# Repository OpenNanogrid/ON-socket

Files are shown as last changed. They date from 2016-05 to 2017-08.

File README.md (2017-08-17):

# ON-socket
Drafts for a smart Extra Low Voltage Direct Current (ELVDC) socket.

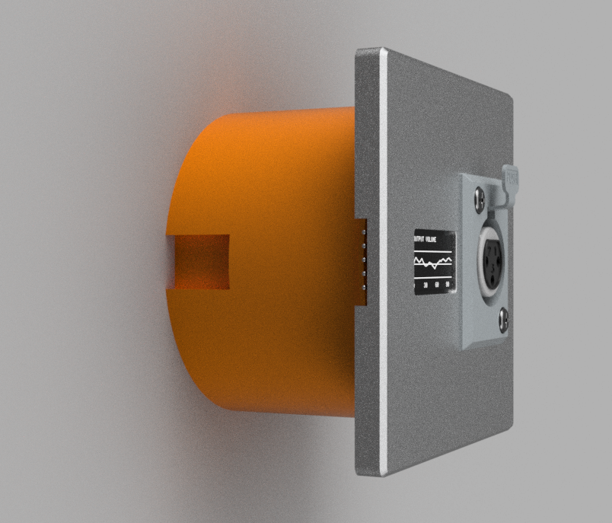
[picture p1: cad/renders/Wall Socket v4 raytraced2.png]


## Components

### Voltage Reference

Needed for precise ADC measurements. 2.56V?

### Switching

1. n-channel MOSFET switching the negative rail, while a common conductor is tied to the positive rail and possibly earth grounded. This will reduce the overhead for gate drivers, charge pumps or p-channel mosfets as switches. What are the downsides to this approach? Voltage sensing will be difficult as the MCU and ADC will be tied at the low side, not floating. A differential sensing with a common voltage higher than the maximum bus voltage is needed.

2. p-channel MOSFET on positive rail. More expensive, Rds worse, but common GND at 0V.

Potential MOSFETs:

	n-Channel
	Name, Rds, Vds, Remark/Price
    IRFS7530-7PPbF, 1.15 mOhm, 60V
    FDMT80060DC, 1.1 mOhm Rds, 60V
    NTMFS5C604NLT1G, 1.2 mOhm, 60V
    NTMFS5C612NLT1G, 1.5 mOhm, 60V, $1.30
    IRLS3036-7PPbF, 1.5 mOhm, 60V
    IRFS7730-7PPbF, 1.7 mOhm, 75V
	CSD18540Q5B, 2.0 mOhm, 60V
    STH315N10F7-2 2.1 mOhm, 100V
    CSD18542KTT, 4.0 mOhm, 60V
    CSD19502Q5B, 4.0 mOhm, 60V
    IRFP4310Z, 4.8 mOhm, TO-247AC
    IRF3205, 8 mOhm, TO-220, cheap
        
Potential gate drivers:

	LM5109B, external bootstrap diode, $0.60
    LM27222, low Iq but max 30V
    TPS7A6350-Q1, 10µA Iq,
    UCC27201A-Q1, 1µA Iq, 120V, $1.60 
    MIC4605

### Current Sensing

1. MOSFET Vds sensing. Only valid if the consumer is a pure current source or current sink. What happens if the gate is discharged and Vds rises to 50V? The following amp and ADC will go into saturation, this needs some more thought. High impedance line from the amp, limited with a diode (crowbar)? Possible if the input impedance is high enough. Temperature drift.

2. PCB shunt. Inexpensive. Needs calibration. Quite high real estate on the PCB. Lowest part count, bidirectional sensing no problem.

3. SMD/THT resistor. Inexpensive but rather large for a high current rating. No calibration needed.

4. Integrated hall effect sensor, e.g. Allegro ACS712. Good efficiency. High price. Sourcing and sinking will both be covered (still needs antiparallel MOSFETs though). (heavy idle: 5V supply, 10mA Iq)

ADCs with integrated amps:
INA220: 12bit Bi-Directional, Zero-Drift, Low- or High-Side, I2C Out Current/Power Monitor, max 26V bus voltage. 1mA Iq
ADS1115: 16bit 4channel 8-800sps ADC with 16x PGA, i2c, differential mode, 150µA Iq
HX711: 24bit (less than 20bit usable) i2c ADC with amplifier, commonly used in weight scales, 1.5mA Iq

### Voltage Sensing

Via high impedance voltage divider into ADC: input voltage, output voltage.

### Arc Sensing

Unplugging a consumer with an inductive load or a high current flow will result in arcing. Can this event be mitigated? How to identify arcing? The resulting plasma will be a large voltage drop right at the plug.

### Micro Controller

8bit with integrated ADC should be sufficient. ESP8266 with integrated WiFi is inexpensive but has high power demands.

### Power Supply

For logic power a low Iq buck converter. Best with synchronous rectification, few external parts.  Potential candidates: TPS54061 (0.09 mA), LM5156 (0.01 mA), LM5009A (0.5 mA), all types up to 60 Vin and about 150mA output.
If the n-channel MOSFET is switched at the high side a gate driver is needed. Power supply for the gate driver needs a separate 10V rail. An LM5007, LM5010 (or an alternative with integrated synchronous rectification and enable input) can be used to form a step down converter to 10V. This step down converter should be shut down with a GPIO pin from the MCU if no load is present, so it needs an enable input.
Although a driver might charge and discharge the FET gate with 1..2A, the charge time is sufficiently low and can be buffered by caps. For a very low switching frequency (ie. using the FET as a power switch) this is fine. When the FET is used to throttle the output (e.g. via BAM / bit ampltitude modulation), the gate driver needs more power.

### Communication

Wireless: NRF24L01+ or WiFi with ESP8266
However, everything should be passive first and work plug and play without having a communication channel. 

### Optional Display

Small OLED

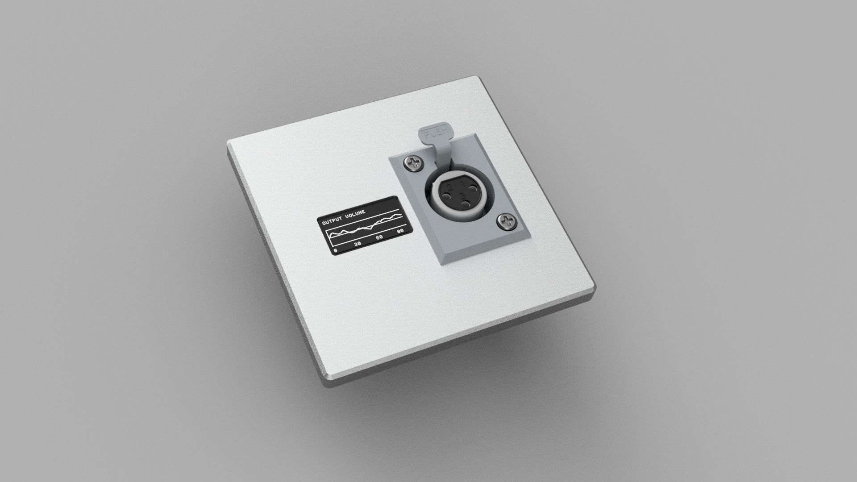
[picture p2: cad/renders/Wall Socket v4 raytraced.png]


## Faults and Errors

1. Overload: Hiccup pattern with recovery time depending on input voltage drop.
1. Short Circuit: Switch output off. Probe current for 1ms every 500ms. Activate output again if current is below threshhold. Needs a more sophisticated algorithm for plug-in events when input capacitors are charged, soft start could be implemented with PWM.
1. Polyfuse? 
1. Diode over output against back-EMF.

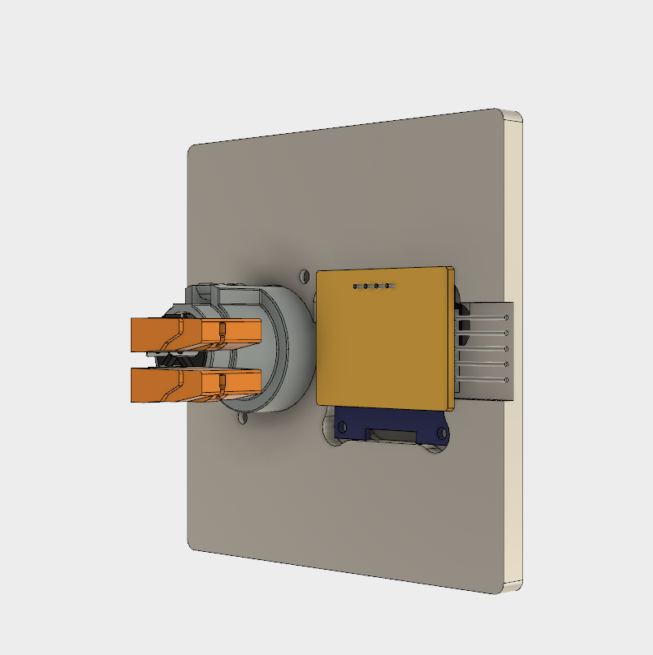
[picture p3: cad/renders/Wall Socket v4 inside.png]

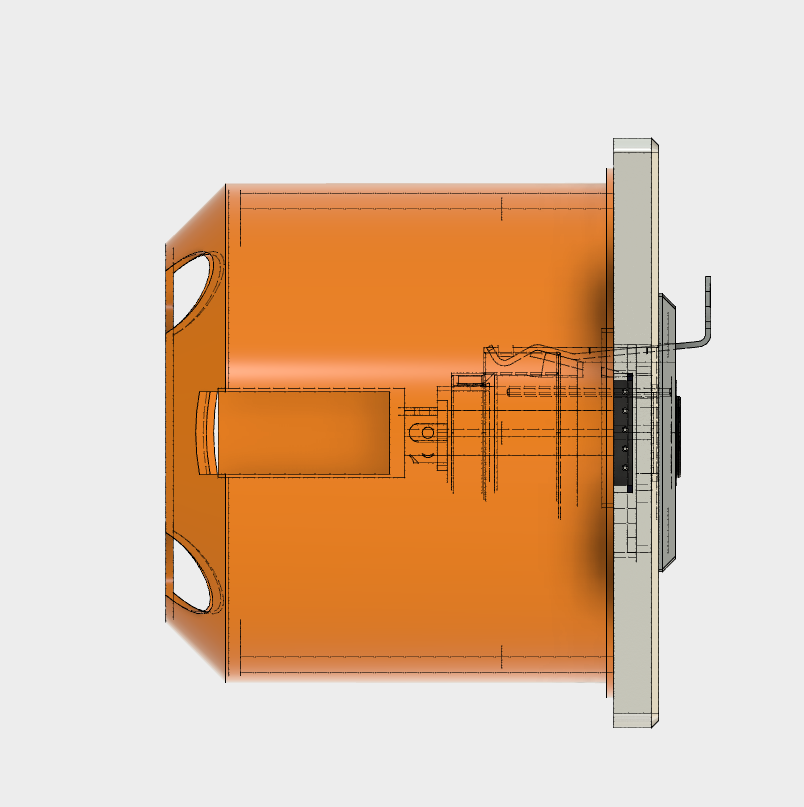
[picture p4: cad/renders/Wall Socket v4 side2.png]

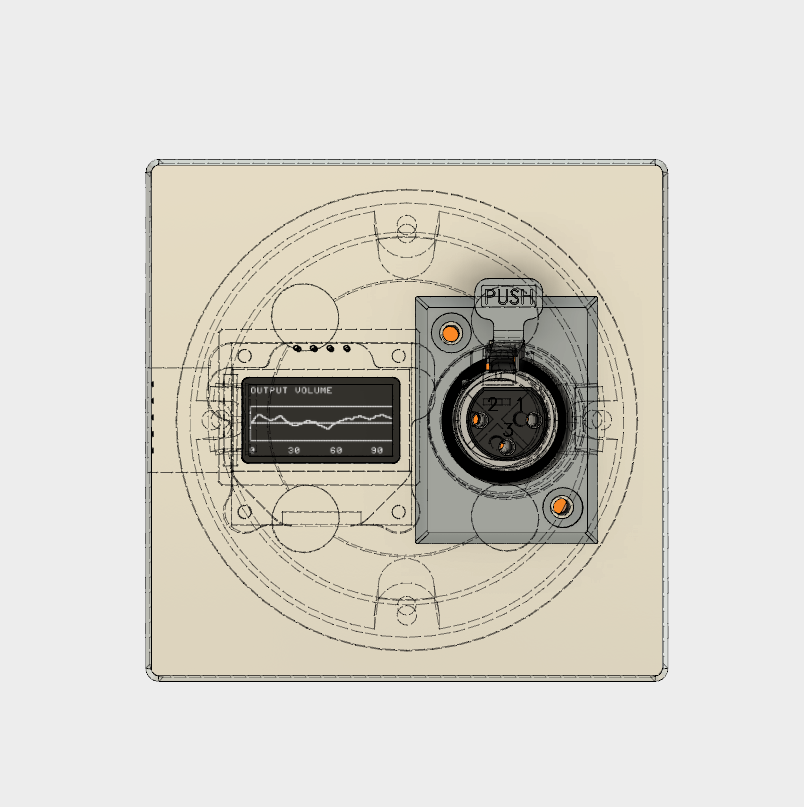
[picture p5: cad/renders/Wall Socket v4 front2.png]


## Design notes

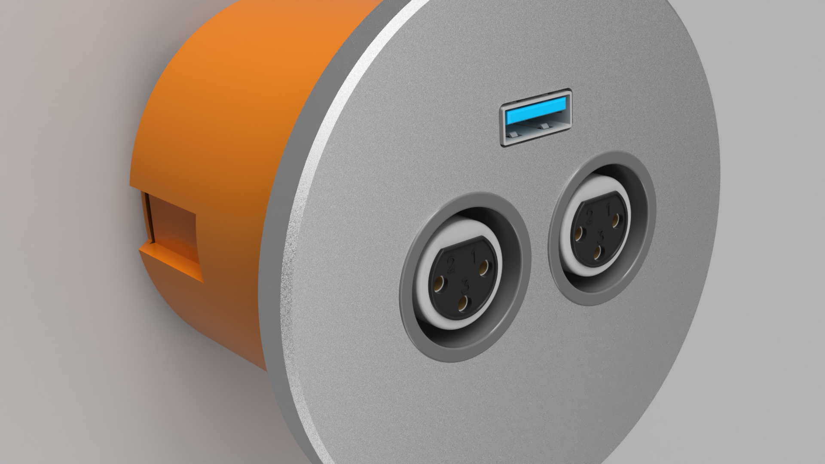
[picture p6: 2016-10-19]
cad/renders/Wall_Socket_Round_Passive_2_x_XLR_+_1_x_USB_2016-Jun-28_02-23-35AM-000_CustomizedView1032985752.png

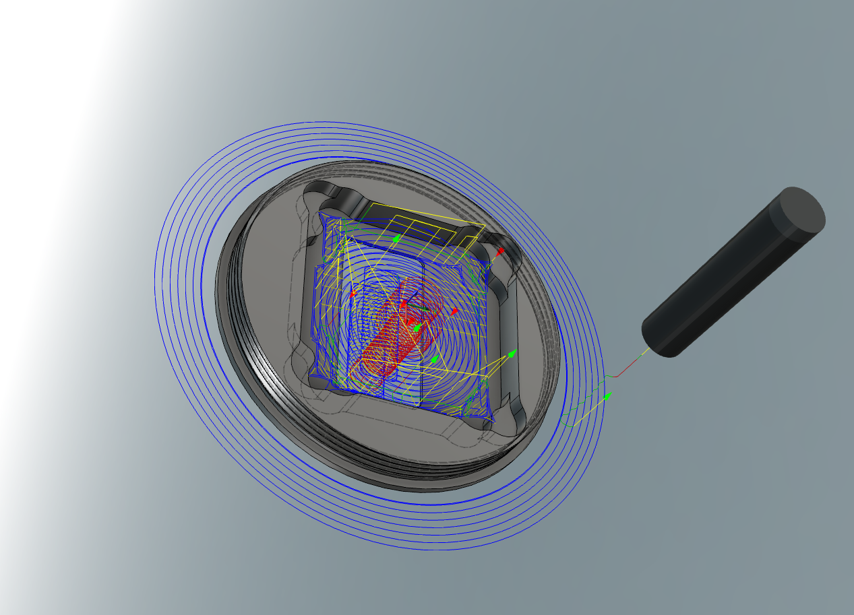
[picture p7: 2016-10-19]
cad/renders/ON Display C44 v4 CAM preview.png

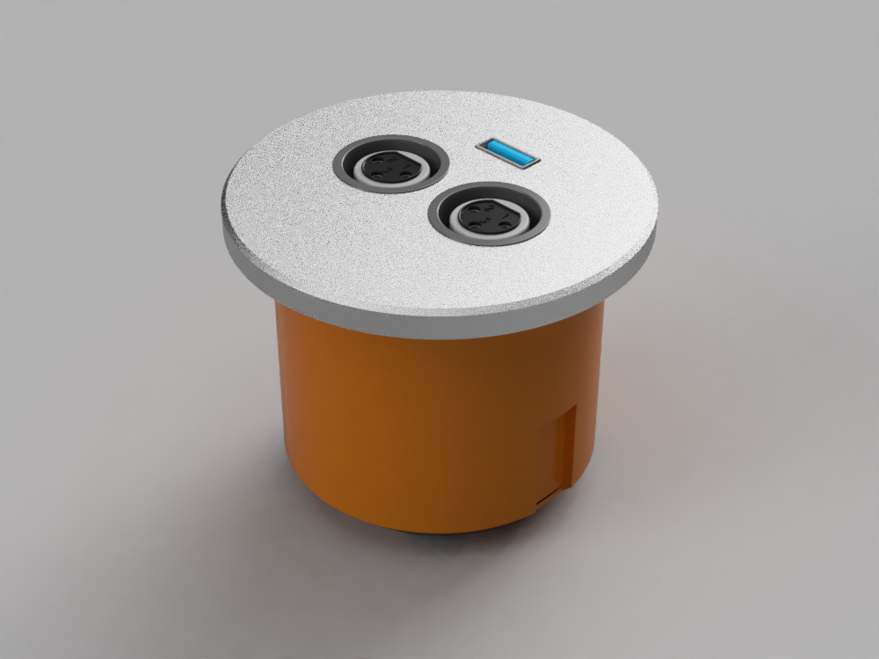
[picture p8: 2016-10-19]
cad/renders/Wall_Socket_Round_Active_2_x_XLR.png

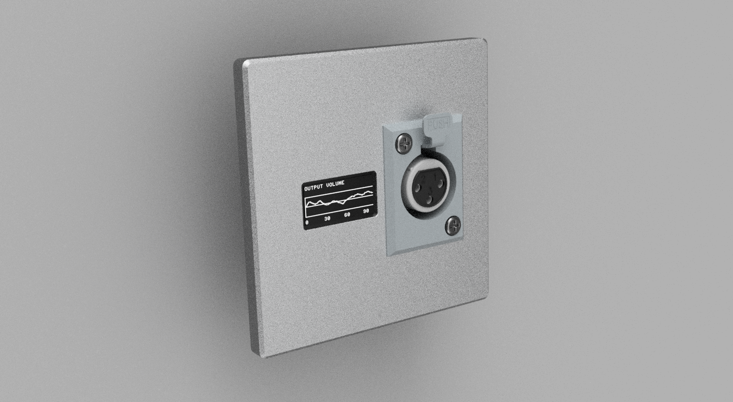
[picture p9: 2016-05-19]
cad/renders/Wall Socket v3.png

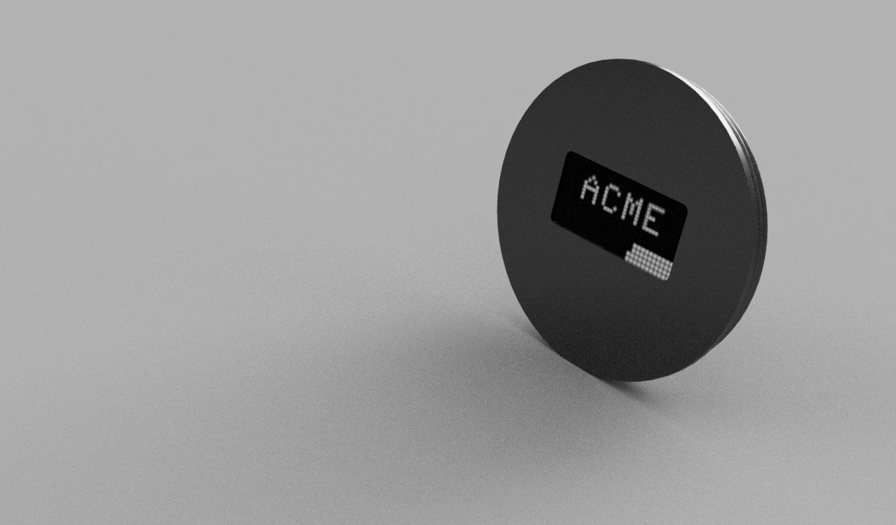
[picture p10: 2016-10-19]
cad/renders/ON Display C44 v4.png

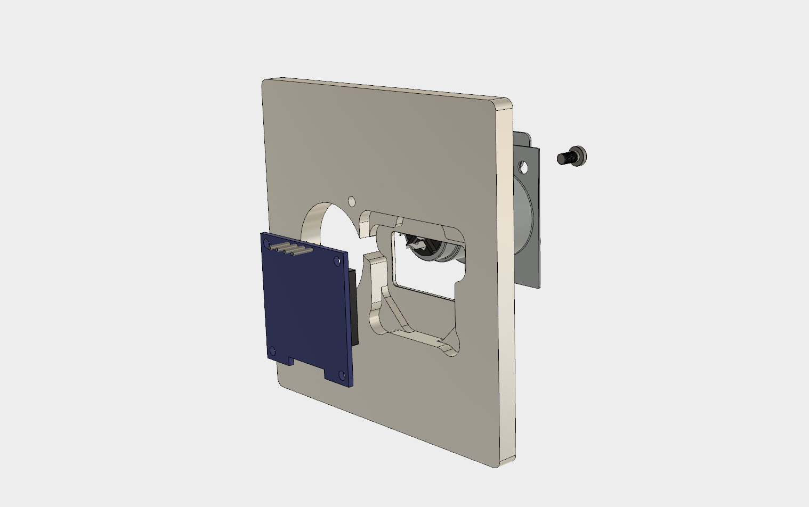
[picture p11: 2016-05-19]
cad/renders/Wall Socket v4.png

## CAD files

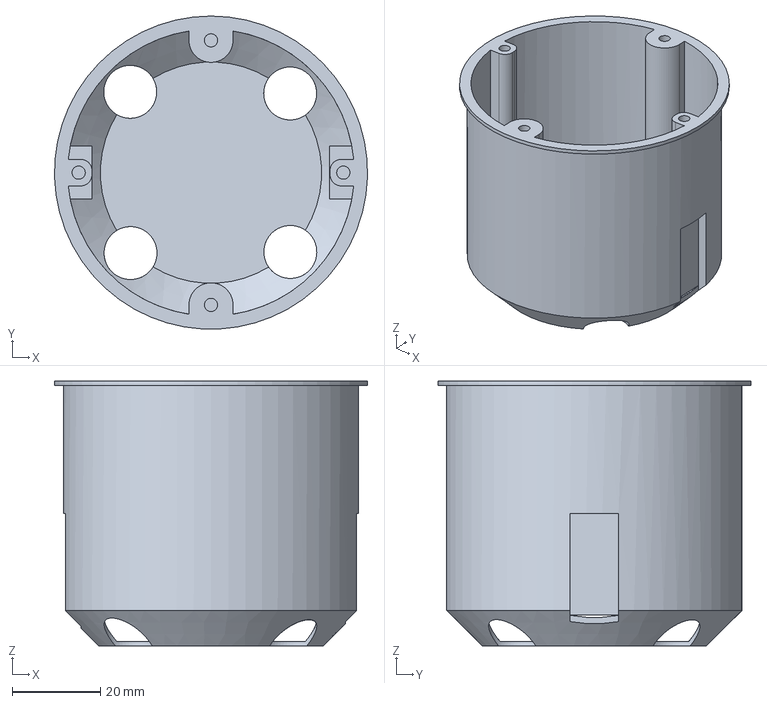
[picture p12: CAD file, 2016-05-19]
cad/Hohlwanddose v1.step
71.0 x 70.9 x 60.0 mm

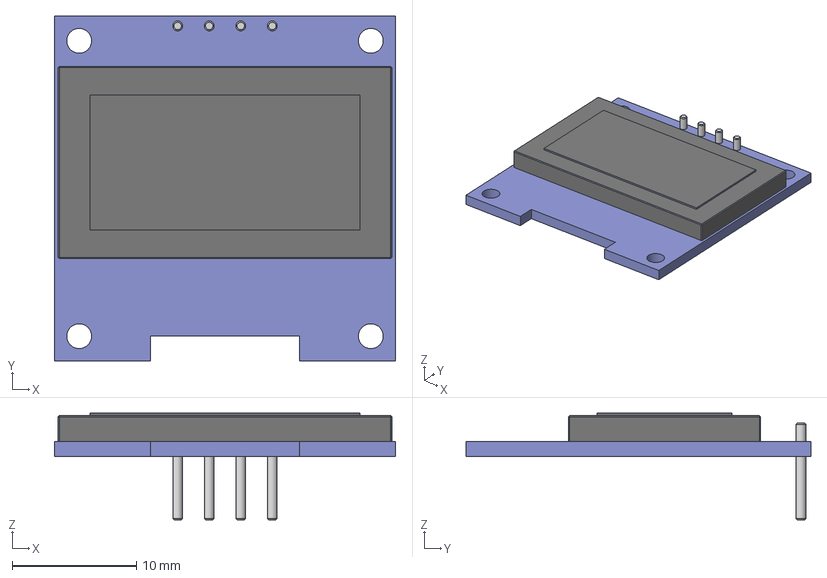
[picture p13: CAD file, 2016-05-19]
cad/OLED Display Module 0.96_ i2c v2.step
27.5 x 27.8 x 8.60 mm

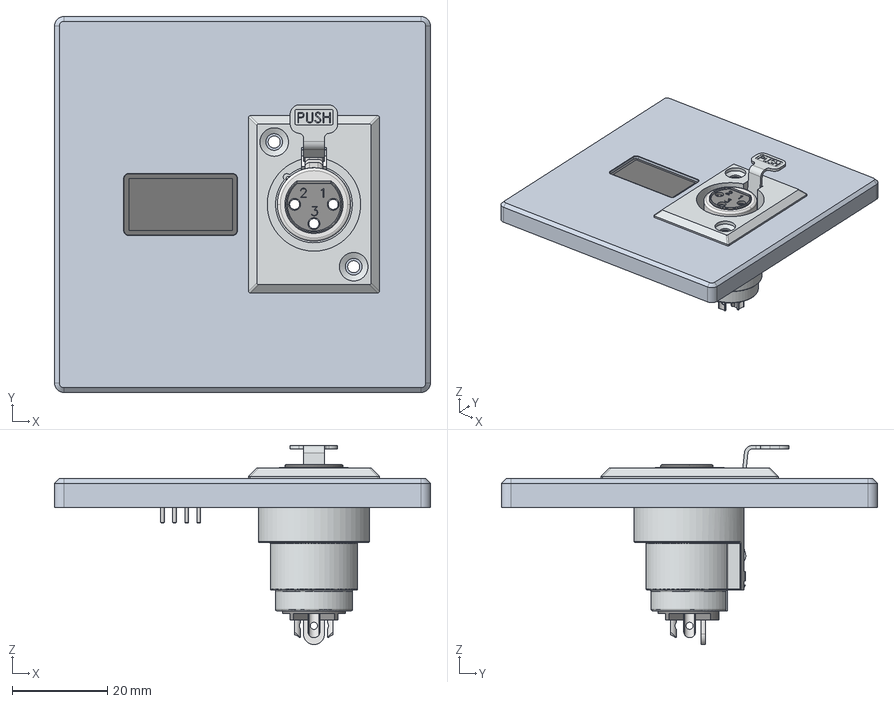
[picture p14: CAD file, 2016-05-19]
cad/Wall Socket v3.step
79.0 x 79.0 x 41.9 mm
XLR Socket Female Neutrik NC3 v2
OLED Display Module 0.96" i2c v2
Face Plate

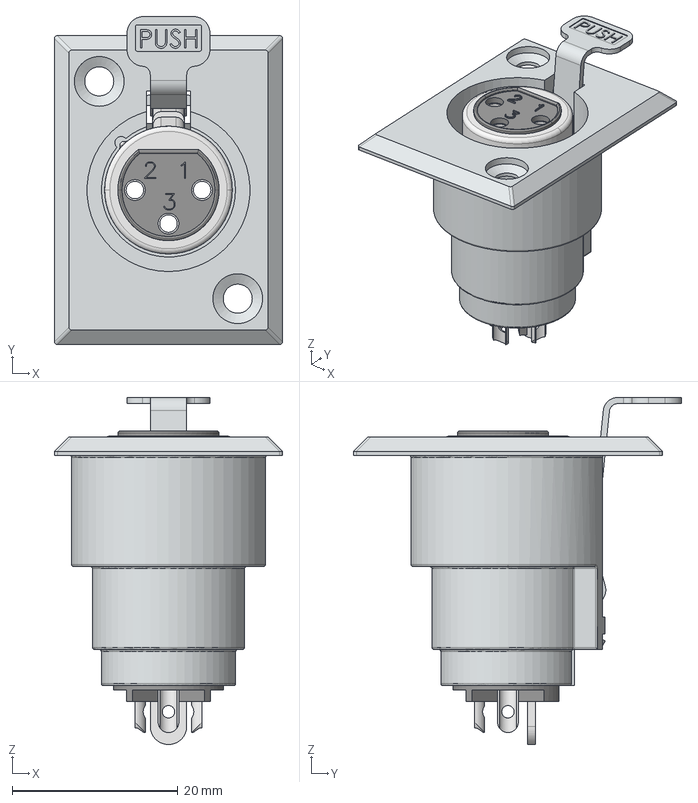
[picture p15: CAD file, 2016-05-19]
cad/XLR Socket Female Neutrik NC3 v2.step
27.5 x 39.6 x 41.9 mm

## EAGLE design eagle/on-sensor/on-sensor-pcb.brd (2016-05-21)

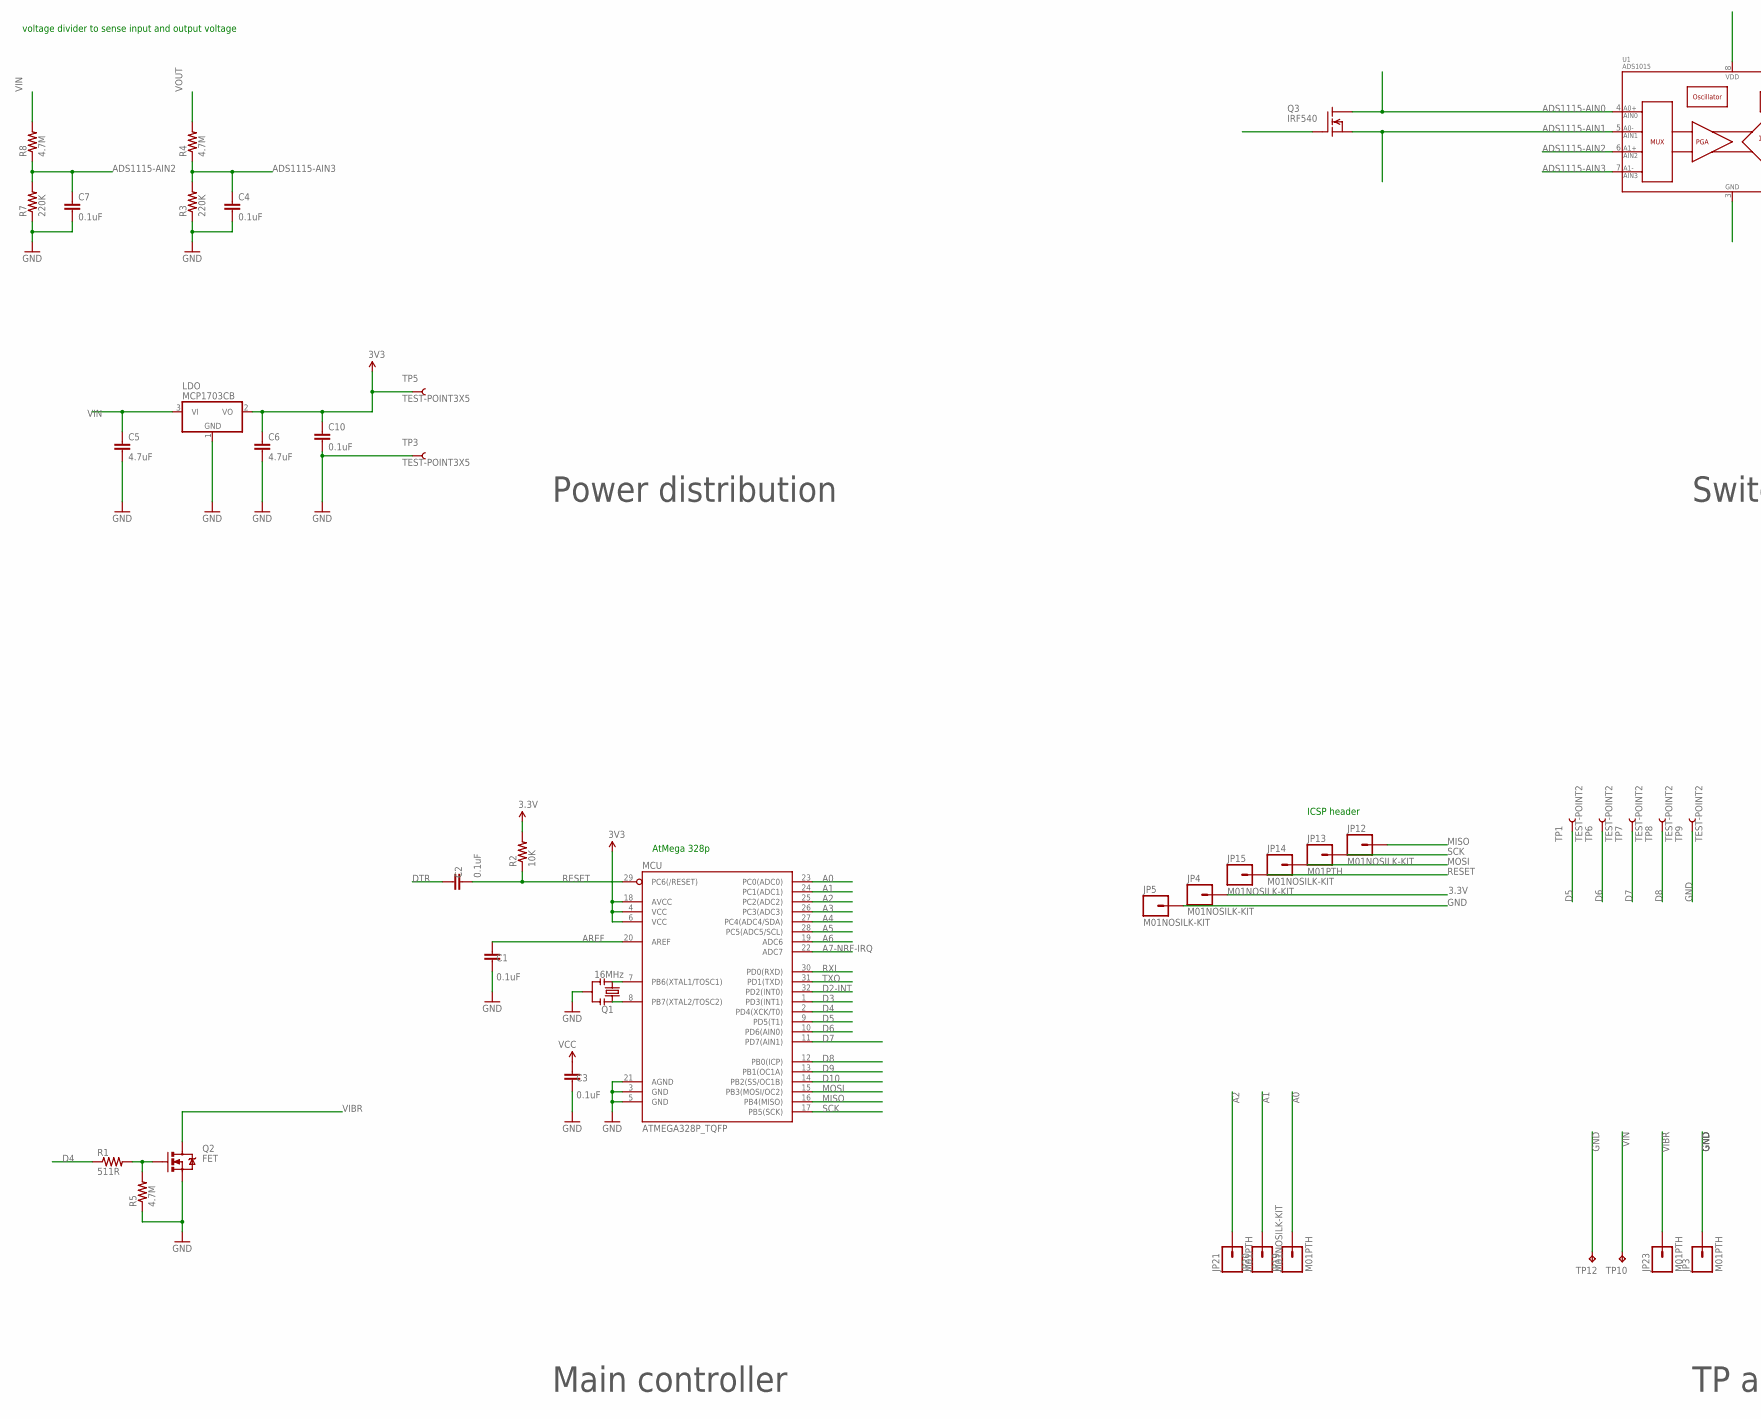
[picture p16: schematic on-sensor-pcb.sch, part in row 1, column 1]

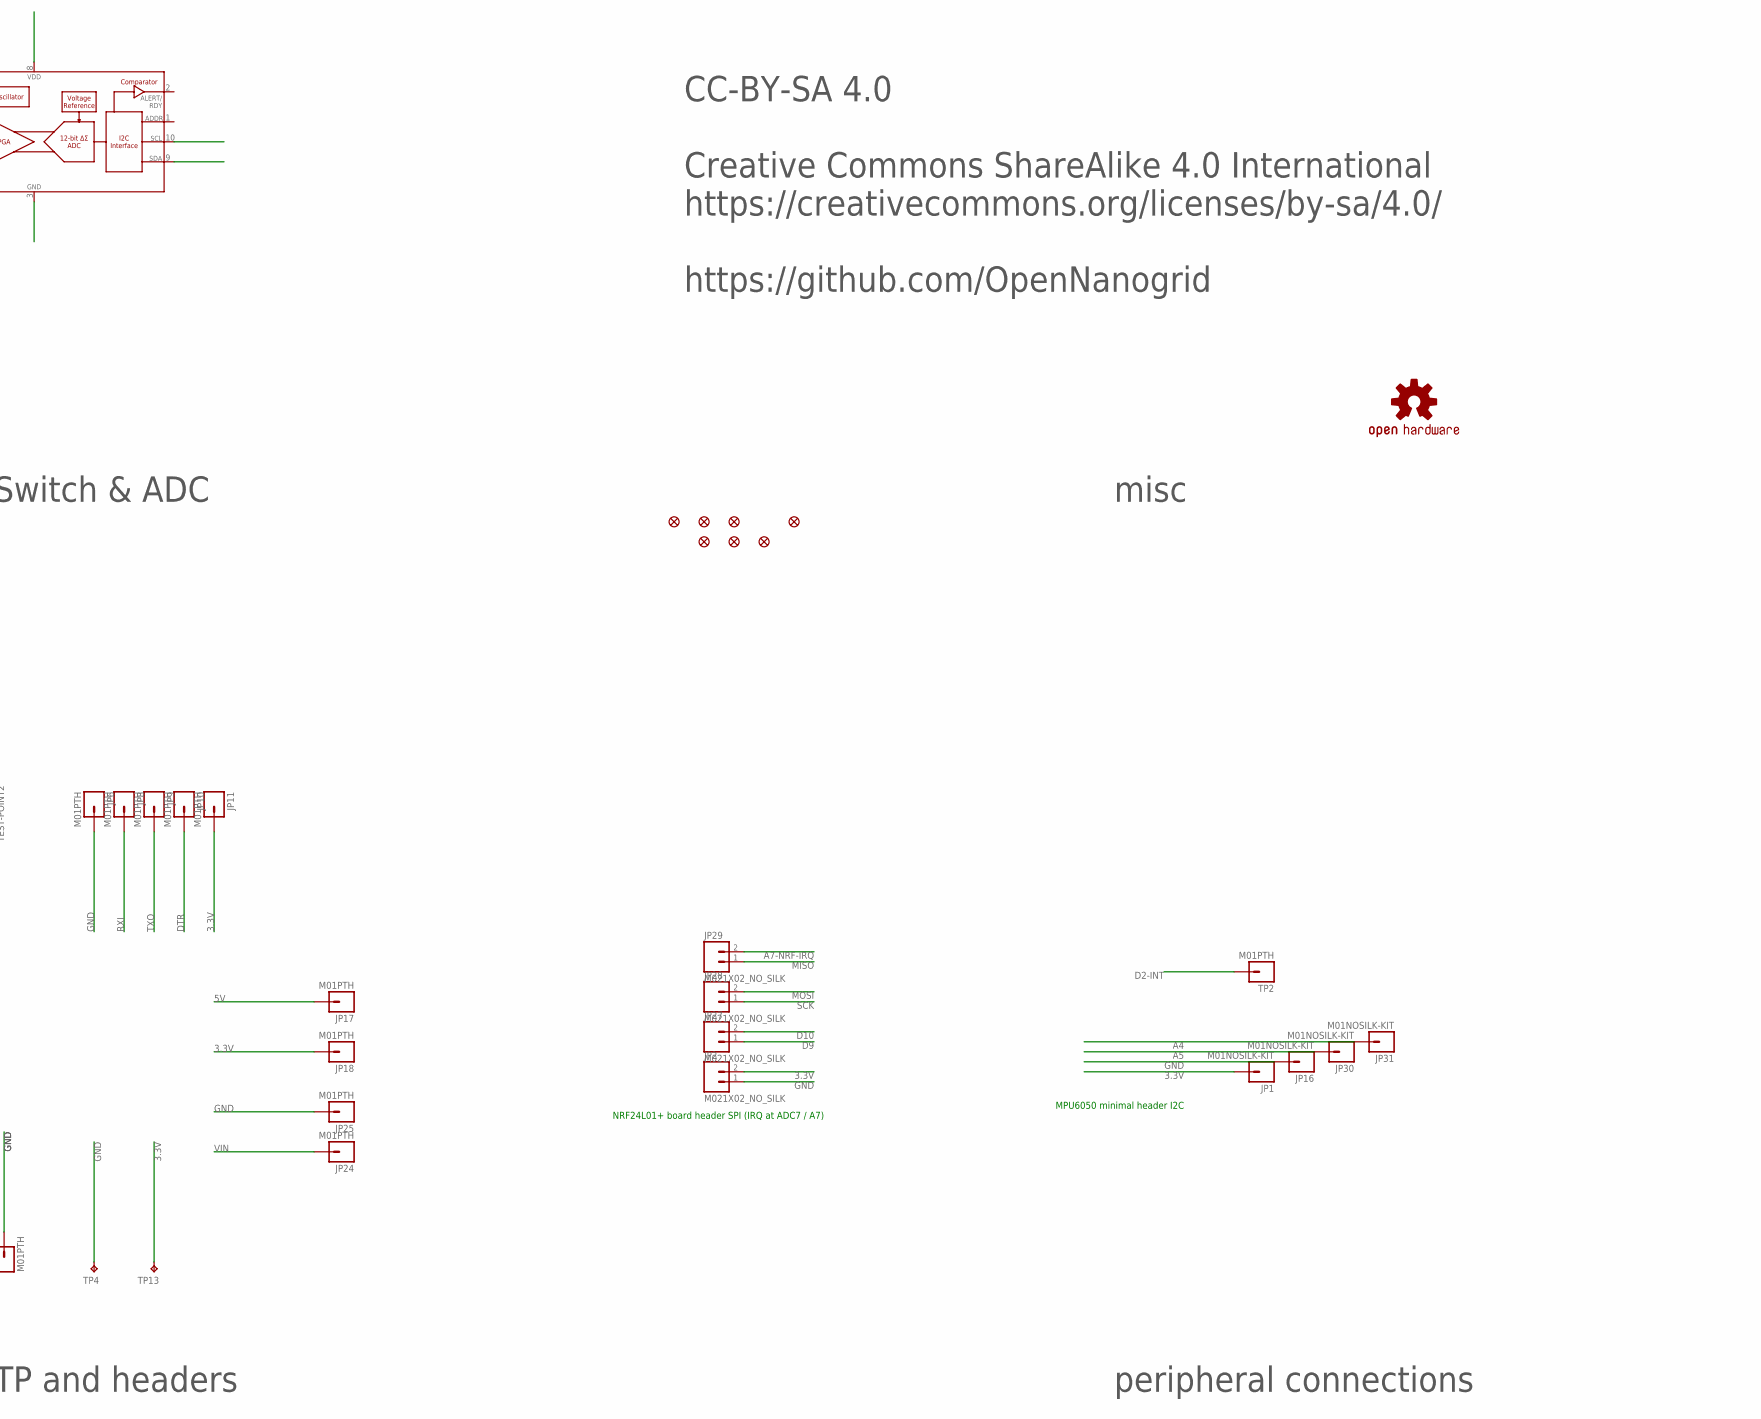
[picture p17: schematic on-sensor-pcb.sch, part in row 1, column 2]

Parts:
C1, C2, C3, C4, C7: 0.1uF; C0402K
C5, C6: 4.7uF; 0603-CAP
C10: 0.1uF; C0603
FID1, FID2, FID3, FID5, FID7, FID8, FID9: FIDUCIALUFIDUCIAL; MICRO-FIDUCIAL
JP1, JP4, JP5, JP12, JP14, JP15, JP16, JP20, JP30, JP31: M01NOSILK-KIT; 1X01NS-KIT
JP2, JP27, JP28, JP29: M021X02_NO_SILK; 1X02_NO_SILK
JP3, JP6, JP8, JP9, JP10, JP11, JP13, JP17, JP18, JP19, JP21, JP23, JP24, JP25: M01PTH; 1X01
LDO: MCP1703CB; SOT23
LOGO1: OSHW-LOGOS; OSHW-LOGO-S
MCU: ATMEGA328P_TQFP; TQFP32-08
Q1: 16MHz; RESONATOR-SMD
Q2: FET; SOT23-3
Q3: IRF540; TO220
R1: 511R; 0603-RES
R2: 10K; 0603-RES
R3, R7: 220K; 0603-RES
R4, R5, R8: 4.7M; 0603-RES
TP1, TP6, TP7, TP8, TP9: TEST-POINT2; PAD.02X.02
TP2: M01PTH; 1X01
TP3, TP5: TEST-POINT3X5; PAD.03X.05
TP4, TP10, TP12, TP13: TPTP20R; TP20R
U1: ADS1015; MSOP10

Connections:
3.3V: C3.2, C6.1, C10.1, JP1.1, JP2.2, JP4.1, JP11.1, JP18.1, LDO.2 (VO), MCU.4 (VCC), MCU.6 (VCC), MCU.18 (AVCC), R2.2, TP5.P$1, TP13.TP
5V: JP17.1
A0: JP19.1, MCU.23 (PC0(ADC0))
A1: JP20.1, MCU.24 (PC1(ADC1))
A2: JP21.1, MCU.25 (PC2(ADC2))
A3: MCU.26 (PC3(ADC3))
A4: JP31.1, MCU.27 (PC4(ADC4/SDA))
A5: JP30.1, MCU.28 (PC5(ADC5/SCL))
A6: MCU.19 (ADC6)
A7-NRF-IRQ: JP29.2, MCU.22 (ADC7)
ADS1115-AIN0: Q3.2 (D), U1.4 (AIN0)
ADS1115-AIN1: Q3.3 (S), U1.5 (AIN1)
ADS1115-AIN2: C7.1, R7.2, R8.1, U1.6 (AIN2)
ADS1115-AIN3: C4.1, R3.2, R4.1, U1.7 (AIN3)
AREF: C1.2, MCU.20 (AREF)
D2-INT: MCU.32 (PD2(INT0)), TP2.1
D3: MCU.1 (PD3(INT1))
D4: MCU.2 (PD4(XCK/T0)), R1.1
D5: MCU.9 (PD5(T1)), TP1.P$1
D6: MCU.10 (PD6(AIN0)), TP6.P$1
D7: MCU.11 (PD7(AIN1)), TP7.P$1
D8: MCU.12 (PB0(ICP)), TP8.P$1
D9: JP27.1, MCU.13 (PB1(OC1A))
D10: JP27.2, MCU.14 (PB2(SS/OC1B))
DTR: C2.2, JP10.1
GND: C1.1, C3.1, C4.2, C5.2, C6.2, C7.2, C10.2, JP2.1, JP3.1, JP5.1, JP6.1, JP16.1, JP25.1, LDO.1 (GND), MCU.3 (GND), MCU.5 (GND), MCU.21 (AGND), Q1.2, Q2.2 (S), R3.1, R5.1, R7.1, TP3.P$1, TP4.TP, TP9.P$1, TP12.TP
MISO: JP12.1, JP29.1, MCU.16 (PB4(MISO))
MOSI: JP14.1, JP28.2, MCU.15 (PB3(MOSI/OC2))
unnamed: MCU.8 (PB7(XTAL2/TOSC2)), Q1.1
unnamed: MCU.7 (PB6(XTAL1/TOSC1)), Q1.3
unnamed: Q2.1 (G), R1.2, R5.2
RESET: C2.1, JP15.1, MCU.29 (PC6(/RESET)), R2.1
RXI: JP8.1, MCU.30 (PD0(RXD))
SCK: JP13.1, JP28.1, MCU.17 (PB5(SCK))
TXO: JP9.1, MCU.31 (PD1(TXD))
VIBR: JP23.1, Q2.3 (D)
VIN: C5.1, JP24.1, LDO.3 (VI), R8.2, TP10.TP
VOUT: R4.2

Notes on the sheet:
NRF24L01+ board header SPI (IRQ at ADC7 / A7)
MPU6050 minimal header I2C
AtMega 328p
voltage divider to sense input and output voltage
ICSP header
Power distribution
Main controller
TP and headers
peripheral connections
misc
Switch & ADC
CC-BY-SA 4.0 Creative Commons ShareAlike 4.0 International https://creativecommons.org/licenses/by-sa/4.0/ https://github.com/OpenNanogrid

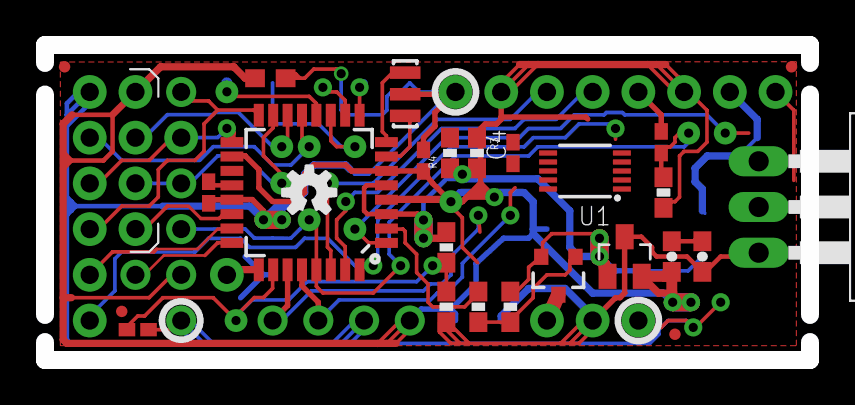
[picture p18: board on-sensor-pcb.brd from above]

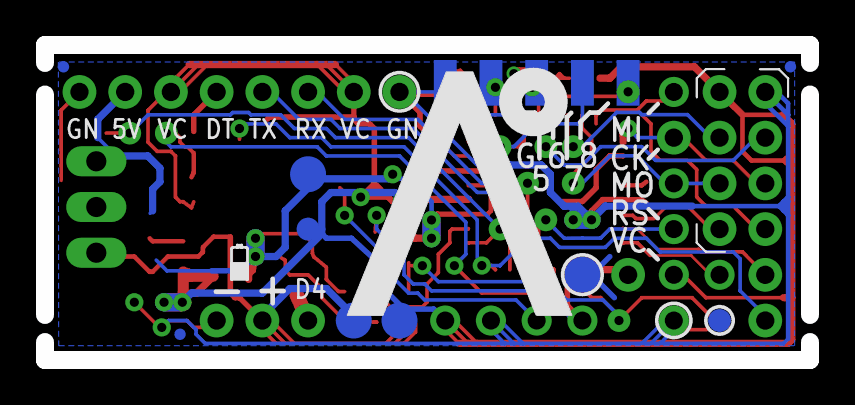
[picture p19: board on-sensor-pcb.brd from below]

Board: 2 copper layers, 42.5 x 17.5 mm, 69 parts (14 on the bottom side), 33 nets.

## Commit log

2016-05-18 create repo
    [on-sensor.brd, on-sensor.kicad_pcb, on-sensor.sch]
2016-05-19 Current sensing
2016-05-19 CAD components for wall outlet
    [Hohlwanddose v1.step, OLED Display Module 0.96_ i2c v2.step, Wall Socket v3.step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]
2016-05-19 rendered CAD files
2016-05-21 Eagle PCB started
    [on-sensor-pcb.brd, on-sensor-pcb.sch]
2016-05-22 Gate driver
2016-05-23 ON Con 32A Wire CAD

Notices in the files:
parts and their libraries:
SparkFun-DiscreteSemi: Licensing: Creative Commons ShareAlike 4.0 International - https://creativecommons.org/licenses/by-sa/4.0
